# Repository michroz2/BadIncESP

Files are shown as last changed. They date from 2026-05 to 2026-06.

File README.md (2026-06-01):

# BadIncESP - Wireless BLE Inclinometer System

[🇷🇺 Русский](#русский) | [🇬🇧 English](#english)

---

## 🇷🇺 Русский

### Описание проекта
**BadIncESP** — это высокоточная двухмодульная беспроводная система измерения и визуализации углов наклона (инклинометр). Цель - обеспечить визуальный контроль «горизонта» при работе со стэдикамом. Может также использоваться для другой фото-видео аппаратуры и проч. Проект разработан для работы в реальном времени с минимальными задержками и состоит из 2-х модулей: передатчика (с безинерционным датчиком углов) и приемника (индикатора), связанных по протоколу Bluetooth Low Energy (BLE).
Система включает фильтр, который автоматически гасит показания крена, если устройство наклоняется вперед или назад.

### Архитектура системы
* **TX Модуль (Передатчик):** Отвечает за опрос I2C-датчика BNO080, вычисление кватернионов, фильтрацию, опрос кнопок управления и работу BLE-сервера. Отправляет данные (Notify) при каждом изменении состояния.
* **RX Модуль (Приемник):** Работает как BLE-клиент с функцией автоматического переподключения. Декодирует команды и выводит плавную анимацию на светодиодную ленту WS2812B (отклонение "капли" от центра с изменением цвета).
* **Память NVS (Preferences):** Все пользовательские настройки (яркость, чувствительность, реверс ленты) и калибровочные нули осей сохраняются в энергонезависимую память обоих устройств. Запись отложена на 15 секунд после последнего действия пользователя по настройке для защиты флэш-памяти от износа.

### Аппаратное обеспечение
| Компонент | Описание / Пин |
| :--- | :--- |
| **TX Микроконтроллер** | ESP32-S3-Zero |
| **Датчик IMU** | BNO080 (I2C: SDA - GPIO5, SCL - GPIO6) |
| **Кнопка управления** | Тактовая кнопка (GPIO9) |
| **Индикатор кнопки (TX)** | Обычный LED (GPIO10) |
| **Системный LED (TX/RX)** | Встроенный WS2812 (GPIO21) или GPIO2 (WROOM) |
| **RX Микроконтроллер** | ESP32-S3-Zero (или NodeMCU ESP32-WROOM) |
| **Основной Индикатор** | Лента WS2812B, 13 светодиодов (Пин данных: GPIO7 или GPIO13) |

### Динамическое демпфирование (Вторая ось)
Вычислитель TX имеет встроенный фильтр тангажа (наклон вперед/назад):
* **0° – 5°:** Зона нечувствительности. Показания крена точны на 100%.
* **5° – 45°:** Зона пропорционального гашения. Показания крена плавно умножаются на понижающий коэффициент от 1.0 до 0.0.
* **> 45°:** Полное гашение. Индикатор крена принудительно устанавливается в центр (0°), независимо от реального угла устройства.

### Управление и Настройка (Кнопка на TX)
Все настройки осуществляются единственной кнопкой на модуле передатчика.

| Действие | Функция | Индикация на ленте (RX) |
| :--- | :--- | :--- |
| **Короткое нажатие (Клик)** | Изменение яркости (4 уровня) | Мгновенное изменение яркости всей ленты |
| **Двойной клик** | Изменение чувствительности (4 уровня) | Симметричное отображение цвета по краям ленты |
| **Удержание (менее 3 сек)** | Установка нового "нуля" (Калибровка) | Вся лента загорается **СИНИМ** цветом |
| **Долгое удержание (> 3 сек)** | Реверс отображения (Смена сторон) | Левая и правая стороны ленты мигают красным/синим |

### Системная LED Индикация (Статус BLE)
Встроенные светодиоды на платах показывают состояние радиоканала:

| Состояние | Цвет системного LED |
| :--- | :--- |
| **Инициализация / Запуск** | Зеленый |
| **Поиск / Ожидание связи (Advertising/Scanning)** | Красный (или мигающий синий на WROOM) |
| **Соединение установлено** | Синий (непрерывный) |
| **Запись в память NVS (RX)** | Центральный пиксель ленты мигает красным 2 раза |

---

## 🇬🇧 English

### Project Overview
**BadIncESP** is a high-precision, dual-module wireless inclinometer system. Designed for real-time operation with minimal latency, it consists of a transmitter (sensor module) and a receiver (indicator module) connected via Bluetooth Low Energy (BLE).

The system not only broadcasts the primary roll angle but also features a built-in mathematical filter (dynamic damping) that automatically zeroes out the roll readings if the device is excessively pitched forward or backward.

### System Architecture
* **TX Module (Transmitter):** Handles BNO080 I2C sensor polling, quaternion math, dynamic filtering, button control logic, and acts as the BLE Server. Dispatches data via BLE Notify instantly upon state changes.
* **RX Module (Receiver):** Operates as a BLE Client with an auto-reconnect routine. Decodes incoming commands and drives smooth animations on a WS2812B LED strip (a shifting "drop" of light indicating angle and severity via color).
* **NVS Memory (Preferences):** User configurations (brightness, sensitivity, strip reverse) and calibration zeroes are saved to non-volatile memory on both devices. Writes are delayed by 15 seconds after the last user input to prevent flash wear.

### Hardware Requirements
| Component | Description / Pin Assignment |
| :--- | :--- |
| **TX Microcontroller** | ESP32-S3-Zero |
| **IMU Sensor** | BNO080 (I2C: SDA - GPIO5, SCL - GPIO6) |
| **Control Button** | Tactile Switch (GPIO9) |
| **Button Feedback (TX)** | Standard LED (GPIO10) |
| **System LED (TX/RX)** | Onboard WS2812 (GPIO21) or GPIO2 (WROOM) |
| **RX Microcontroller** | ESP32-S3-Zero (or NodeMCU ESP32-WROOM) |
| **Main Indicator** | WS2812B Strip, 13 LEDs (Data Pin: GPIO7 or GPIO13) |

### Dynamic Damping (Y-Axis Filter)
The TX processor includes a pitch (forward/backward tilt) filter:
* **0° – 5°:** Deadzone. Roll readings are 100% accurate and unaffected.
* **5° – 45°:** Proportional damping zone. The roll output is smoothly multiplied by a reduction factor from 1.0 down to 0.0.
* **> 45°:** Complete damping. The roll indicator is forced to the center (0°), regardless of the actual device roll.

### Controls & Configuration (TX Button)
All system settings are managed via a single button on the Transmitter module.

| Action | Function | RX Strip Indication |
| :--- | :--- | :--- |
| **Single Click** | Change Brightness (4 levels) | Immediate brightness update across the strip |
| **Double Click** | Change Sensitivity (4 levels) | Symmetrical color blocks light up on the strip edges |
| **Hold (< 3 sec) & Release** | Set Calibration "Zero" | The entire strip flashes **BLUE** |
| **Long Hold (> 3 sec)** | Reverse Display (Swap Left/Right) | Left and right halves alternate Red/Blue |

### System LED Status (BLE Link)
Onboard processor LEDs provide immediate feedback on the radio link status:

| State | System LED Color |
| :--- | :--- |
| **Booting / Init** | Green |
| **Scanning / Advertising (No Link)** | Red (or flashing Blue on WROOM boards) |
| **BLE Connected** | Blue (Solid) |
| **NVS Memory Write (RX)** | The center LED of the strip flashes Red twice |

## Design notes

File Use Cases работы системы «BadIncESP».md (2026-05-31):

### **Use Cases работы системы «BadIncESP»**

#### **1\. Включение, инициализация**

* **Действия TX:** 1\. Инициализация шины I2C и датчика BNO080. 2\. Чтение из энергонезависимой памяти (EEPROM) сохраненных настроек: яркость (`curFade`), чувствительность (`curSensitivity`), инверсия (`revers`), угол калибровки нуля (`deltaZero`). 3\. Инициализация радиомодуля (сейчас LoRa, будет BLE). 4\. Отправка команды приветствия `CMD_GREETING` на RX.  
* **Действия RX:**  
  1. Чтение из энергонезависимой памяти своих копий настроек (яркость, чувствительность, инверсия).  
  2. Инициализация светодиодной ленты WS2812B с сохраненной яркостью.  
  3. Инициализация радиомодуля на приём.  
  4. При получении `CMD_GREETING` — проигрывание анимации приветствия (пробегание красного, зеленого, синего цветов по всей ленте). Запуск таймера перехода в спящий режим (StandByTime \= 30 сек).

#### **2\. Основная работа (получение, пересылка углов, индикация)**

* **Действия TX:**  
  1. Непрерывный опрос датчика BNO080 (Pitch/Roll).  
  2. Применение к полученному углу поправки `deltaZero` (калибровки).  
  3. Вычисление номера режима индикации (`curMode` от 0 до 22\) на основе текущего угла и выбранной таблицы чувствительности (`modeRange`).  
  4. Если вычисленный `curMode` изменился по сравнению с предыдущим шагом, отправка команды `CMD_MODE` с новым значением по радиоканалу.  
* **Действия RX:**  
  1. Ожидание команд по радиоканалу.  
  2. При получении `CMD_MODE`: обновление таймера спящего режима. Копирование паттерна свечения из массива `modes` согласно полученному индексу.  
  3. Если включен реверс (`revers`), паттерн разворачивается зеркально.  
  4. Вывод паттерна на ленту (`FastLED.show()`).  
  5. Если команды не поступают более 30 секунд: RX показывает анимацию отключения (мигание синим по центру) и гасит ленту до получения новых данных.

#### **3\. Настройки системы (Нажатия кнопки на TX)**

Вся обработка нажатий кнопки физически происходит на модуле TX. RX только показывает анимации и обновляет переменные.

* **Короткое нажатие (Изменение яркости):**  
  * *TX:* Переключает `curFade` (циклично), отправляет `CMD_BRIGHTNESS`, запускает таймер отложенной записи в память (15 секунд).  
  * *RX:* Применяет новую глобальную яркость к ленте, перерисовывает текущий паттерн крена.  
* **Двойное нажатие (Изменение чувствительности):**  
  * *TX:* Переключает `curSensitivity` (циклично), отправляет `CMD_SENSITIVITY`, запускает таймер записи в память.  
  * *RX:* Показывает анимацию чувствительности (симметрично загораются 2 светодиода, расстояние между которыми зависит от уровня чувствительности).  
* **Длинное нажатие — Удержание (Подготовка к калибровке):**  
  * *TX:* Фиксирует старт долгого нажатия, отправляет `CMD_LONGPRESS`. Запускает таймер 3 секунды.  
  * *RX:* Показывает «двойную радугу» (`modeLongPressStart`).  
* **Длинное нажатие — Отпускание до 3-х секунд (Калибровка нуля):**  
  * *TX:* Останавливает опросы. Делает 100 замеров с датчика BNO080, вычисляет среднее значение и записывает его в `deltaZero`. Отправляет `CMD_CALIBRATION`. Запускает таймер записи в память.  
  * *RX:* Заливает всю ленту синим цветом в знак успешной калибровки.  
* **Очень длинное нажатие — Более 3-х секунд (Инверсия сторон):**  
  * *TX:* Инвертирует флаг `revers`, отправляет `CMD_SWITCHSIDES`. Отменяет режим калибровки. Запускает таймер записи в память.  
  * *RX:* Проигрывает анимацию смены сторон (синяя и красная половины ленты меняются местами).  
* **Автоматическое сохранение (Отложенная запись):**  
  * *TX:* Если с момента последней настройки прошло 15 секунд (и кнопка не нажималась), TX сохраняет свои настройки в EEPROM и отправляет `CMD_EEPROM_WRITE`.  
  * *RX:* При получении команды показывает анимацию записи (мигание центрального светодиода красным) и сохраняет свои текущие переменные в свой EEPROM.

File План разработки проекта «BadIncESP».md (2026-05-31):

### **План разработки проекта «BadIncESP»**

**Этап 1: Анализ существующей системы и проектирование (Новый шаг)**

* **Шаг 1.1:** Получение текущего кода (TX и RX) и имеющейся документации.  
* **Шаг 1.2:** Изучение логики работы BNO080 и WS2812B в старом коде.  
* **Шаг 1.3:** Составление Use Cases работы системы (включая передачу углов в реальном времени и логику работы кнопки настроек на TX). Утверждение архитектуры взаимодействия.

**Этап 2: Подготовка инфраструктуры и даташитов**

* **Шаг 2.1:** Изучение даташитов ESP32-S3-Zero (распиновка, аппаратные особенности).  
* **Шаг 2.2:** Создание двух чистых проектов PlatformIO (TX и RX) с настройкой конфигураций `platformio.ini`. Фиксация пинов.

**Этап 3: Базовое портирование периферии (Без радиосвязи)**

* **Шаг 3.1 (TX):** Интеграция опроса BNO080 и кнопки. Вывод данных в Serial.  
* **Шаг 3.2 (RX):** Интеграция управления WS2812B (с учетом использования аппаратного RMT ESP32 для избежания блокировок). Тестовая индикация.

**Этап 4: Разработка канала связи BLE на максимальной скорости**

* **Шаг 4.1 (TX \- Server):** Поднятие BLE Сервера, создание сервиса и характеристик для углов и команд кнопки. Настройка механизма Notify.  
* **Шаг 4.2 (RX \- Client):** Поднятие BLE Клиента, подключение к TX, подписка на Notify. Вывод получаемых данных в Serial.

**Этап 5: Полная интеграция системы**

* Связывание потока данных BLE (RX) с логикой отображения WS2812B.  
* Тестирование скорости отклика, обработка потери/восстановления связи.

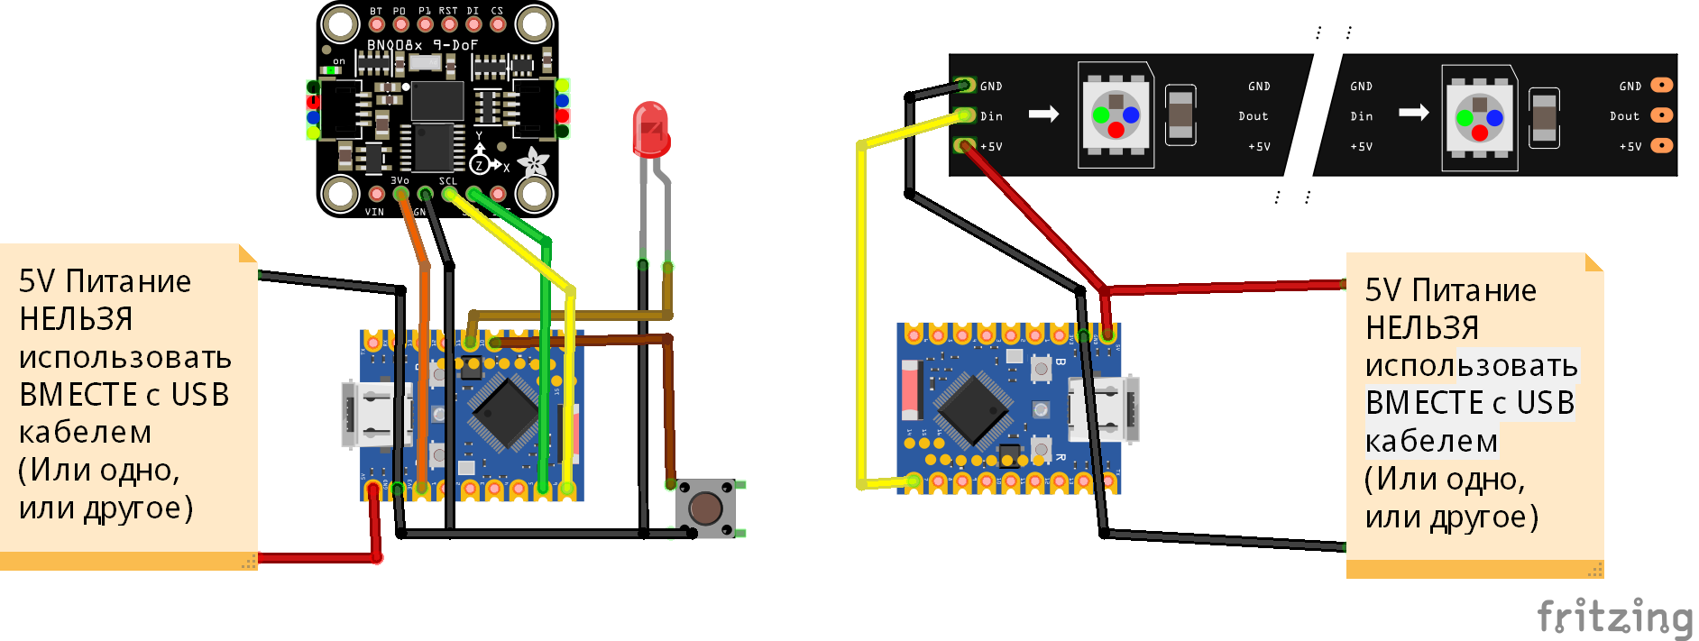
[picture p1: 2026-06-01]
BadIncESP_bb.png

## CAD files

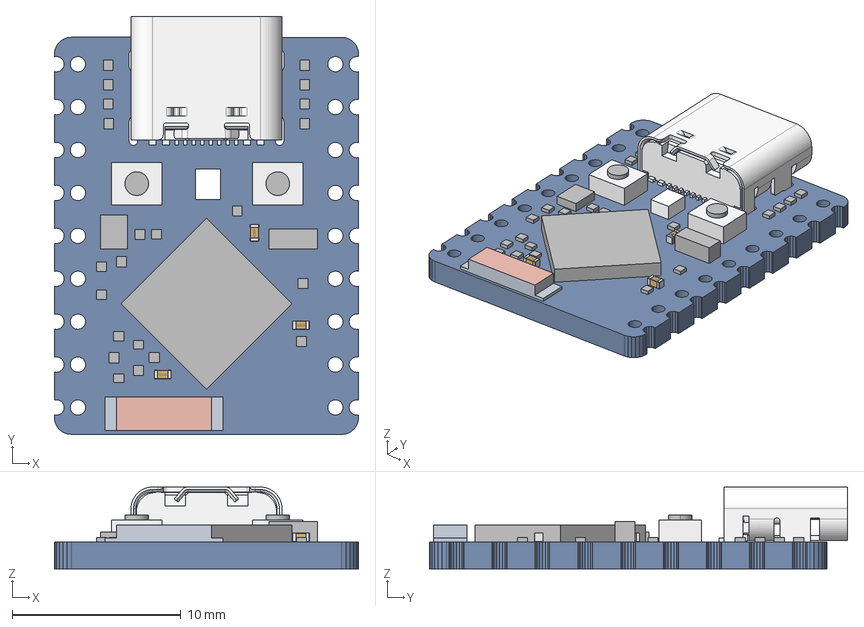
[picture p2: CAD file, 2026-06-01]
ESP32-S3-Zero_v2-138eb3753cf14afa3252058c380ca416.stp
18.0 x 24.7 x 4.85 mm
BOARD
EXTRUDED-21020 x 13
EXTRUDED-21415 x 7
3_1_A x 3
EXTRUDED-58116 x 2
EXTRUDED-58651
EXTRUDED-59046
EXTRUDED-59609
TYPE-C_16PIN-9X3X7_3
PRT0001
C3
BUTTON-2X3XH1_5

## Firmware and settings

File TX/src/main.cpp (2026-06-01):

/**
 * @file main.cpp
 * @project BadIncESP - Модуль TX (Датчик и вычислитель)
 * @version 1.6
 * * @changelog
 * v1.6 - Реализовано плавное гашение угла по оси Y в диапазоне 5-45 градусов.
 * - Добавлена калибровка нуля для оси Y (deltaZero_Y) с сохранением в Preferences.
 * v1.5 - Замена старой EEPROM на Preferences.h. Отложенная запись 15 секунд.
 * v1.1.1 - Исправление BLE: включен ScanResponse(true) для передачи UUID.
 * v1.1 - Замена LoRa на BLE Server с Notify. Статусный RGB LED (GPIO 21).
 * v1.0 - Первичное портирование периферии (BNO080, Кнопка, Статусный LED).
 */

 #include <Arduino.h>
 #include <Wire.h>
 #include "SparkFun_BNO080_Arduino_Library.h"
 #include <OneButton.h>
 #include <FastLED.h>
 #include <Preferences.h> 
 
 // Подключение библиотек BLE
 #include <BLEDevice.h>
 #include <BLEServer.h>
 #include <BLEUtils.h>
 #include <BLE2902.h>
 
 // ================= ОПРЕДЕЛЕНИЕ ВЕРСИИ И ТИПА МОДУЛЯ =================
 #define MODULE_TYPE "TX (ДАТЧИК)"
 #define VERSION     "1.6"
 
 // ================= НАСТРОЙКИ ПИНОВ ESP32-S3 =================
 #define PIN_I2C_SDA 5
 #define PIN_I2C_SCL 6
 #define PIN_CONTROL_BUTTON 9
 #define PIN_FB_LED 10
 #define PIN_SYS_LED 21  // Встроенный адресный RGB LED
 
 // ================= НАСТРОЙКИ BLE =================
 #define SERVICE_UUID        "4fafc201-1fb5-459e-8fcc-c5c9c331914b"
 #define CHARACTERISTIC_UUID "beb5483e-36e1-4688-b7f5-ea07361b26a8"
 
 BLEServer* pServer = NULL;
 BLECharacteristic* pCharacteristic = NULL;
 bool deviceConnected = false;
 bool oldDeviceConnected = false;
 
 // ================= ОСНОВНЫЕ НАСТРОЙКИ =================
 #define USE_X_AXIS 1  
 #define USE_Y_AXIS 0  
 bool usedAxis = USE_X_AXIS;    
 
 #define FB_LED_BRIGHTNESS 30   
 #define NUM_MODES 23           
 #define NUM_FADES 4            
 #define NUM_SENSITIVITIES 4    
 #define VERY_LONG_PRESS_MS 3000 
 
 // ================= НАСТРОЙКИ ГАШЕНИЯ ПО ОСИ Y =================
 const float DEADZONE_ANGLE_Y = 5.0f;      // До этого угла (градусы) влияние Y игнорируется
 const float MAX_DAMPING_ANGLE_Y = 45.0f;  // При этом угле и выше, основной угол принудительно гасится в 0.0
 
 // Команды для связи
 #define CMD_BRIGHTNESS       100 
 #define CMD_SENSITIVITY      101 
 #define CMD_SWITCHSIDES      102 
 #define CMD_LONGPRESS        103 
 #define CMD_CALIBRATION      104 
 #define CMD_MODE             111 
 #define CMD_GREETING         112 
 #define CMD_EEPROM_WRITE     113 
 
 // Настройки таймера сохранения памяти NVS
 #define WRITE_PREFERENCES_DELAY_MS 15000 
 Preferences prefs;
 bool writePrefsPending = false;
 uint32_t writePrefsTimer = 0;
 
 // Дефолтные значения параметров
 const byte defaultFade = 0;
 const byte defaultSensitivity = 0;
 const boolean defaultReverse = false;
 const float defaultDeltaZero = 0.0f;
 
 // ================= ГЛОБАЛЬНЫЕ ОБЪЕКТЫ =================
 BNO080 myIMU;
 OneButton buttonControl(PIN_CONTROL_BUTTON, true);
 CRGB sysLed[1]; 
 
 // ================= ГЛОБАЛЬНЫЕ ПЕРЕМЕННЫЕ СОСТОЯНИЯ =================
 byte curFade = defaultFade; 
 byte curMode = NUM_MODES / 2; 
 byte prevMode = -1; 
 float Roll = 0.0f;   
 float deltaZero = defaultDeltaZero; 
 float deltaZero_Y = defaultDeltaZero; // Калибровочный ноль перпендикулярной оси Y
 boolean revers = defaultReverse;   
 byte curSensitivity = defaultSensitivity;    
 
 boolean startCalibrationMode = false;
 uint32_t verylongPressTimer = 0;
 
 uint8_t fades[NUM_FADES] = {255, 64, 32, 8}; 
 
 const float modeRange[NUM_SENSITIVITIES][NUM_MODES - 1] PROGMEM = 
 {
   {10, 5.0, 2.2, 1.6, 1.1, 0.8, 0.6, 0.4, 0.3, 0.2, 0.1,  -0.1, -0.2, -0.3, -0.4, -0.6, -0.8, -1.1, -1.6, -2.2, -5.0, -10},
   {10, 5.0, 2.8, 2.1, 1.5, 1.1, 0.8, 0.5, 0.4, 0.3, 0.2,  -0.2, -0.3, -0.4, -0.5, -0.8, -1.1, -1.5, -2.1, -2.8, -5.0, -10},
   {10, 5.0, 3.4, 2.6, 1.9, 1.4, 1.0, 0.6, 0.5, 0.4, 0.3,  -0.3, -0.4, -0.5, -0.6, -1.0, -1.4, -1.9, -2.6, -3.4, -5.0, -10},
   {12, 6.0, 4.0, 3.1, 2.3, 1.7, 1.2, 0.7, 0.6, 0.5, 0.4,  -0.4, -0.5, -0.6, -0.7, -1.2, -1.7, -2.3, -3.1, -4.0, -6.0, -12},
 };
 
 // ================= ПРОТОТИПЫ ФУНКЦИЙ =================
 void updateFBLed(bool ledStatus);
 void flashFBLed(int times);
 void setSysLed(CRGB color);
 void sendLoRaMessage(byte msgCmd, byte sndData);
 void preparePreferencesWrite();
 void processPreferences();
 void loadSettings();
 void saveSettings();
 void setZERO();
 
 // ================= CALLBACKS ДЛЯ BLE =================
 class MyServerCallbacks: public BLEServerCallbacks {
     void onConnect(BLEServer* pServer) {
       deviceConnected = true;
     };
     void onDisconnect(BLEServer* pServer) {
       deviceConnected = false;
     }
 };
 
 // ================= РАБОТА С ЭНЕРГОНЕЗАВИМОЙ ПАМЯТЬЮ (NVS) =================
 void loadSettings() {
   Serial.println("Чтение настроек из памяти NVS...");
   prefs.begin("badinc", true); 
   
   curFade = prefs.getUChar("fade", defaultFade);
   curSensitivity = prefs.getUChar("sens", defaultSensitivity);
   revers = prefs.getBool("rev", defaultReverse);
   deltaZero = prefs.getFloat("zero", defaultDeltaZero);
   deltaZero_Y = prefs.getFloat("zero_y", defaultDeltaZero); // Загрузка нуля оси Y
   
   prefs.end();
 
   Serial.printf("Загружено: Яркость=%d, Чувствительность=%d, Реверс=%d, Ноль_X=%6.2f°, Ноль_Y=%6.2f°\n", 
                 curFade, curSensitivity, revers, deltaZero, deltaZero_Y);
 }
 
 void saveSettings() {
   Serial.println("ФАКТИЧЕСКОЕ СОХРАНЕНИЕ настроек в память NVS...");
   prefs.begin("badinc", false); 
   
   prefs.putUChar("fade", curFade);
   prefs.putUChar("sens", curSensitivity);
   prefs.putBool("rev", revers);
   prefs.putFloat("zero", deltaZero);
   prefs.putFloat("zero_y", deltaZero_Y); // Сохранение нуля оси Y
   
   prefs.end();
   Serial.println("Сохранение успешно выполнено.");
 }
 
 void preparePreferencesWrite() {
   writePrefsPending = true;
   writePrefsTimer = millis() + WRITE_PREFERENCES_DELAY_MS;
   Serial.println("Память: запланирована отложенная запись через 15 секунд.");
 }
 
 void processPreferences() {
   if (writePrefsPending && (millis() > writePrefsTimer)) {
     writePrefsPending = false;
     saveSettings();
     sendLoRaMessage(CMD_EEPROM_WRITE, 0);
     flashFBLed(3); 
     prevMode = -1; 
   }
 }
 
 // ================= АППАРАТНЫЕ ФУНКЦИИ (LEDs) =================
 void initFBled() {
   pinMode(PIN_FB_LED, OUTPUT);
   analogWrite(PIN_FB_LED, 0); 
   updateFBLed(1);
 }
 
 void updateFBLed(bool ledStatus) {
   analogWrite(PIN_FB_LED, ledStatus ? FB_LED_BRIGHTNESS : 0);
 }
 
 void flashFBLed(int times) {
   bool flash = false;
   for (int i = 0; i < times * 2; i++) {
     flash = !flash;
     updateFBLed(flash);
     delay(200);
   }
   delay(200);
 }
 
 void setSysLed(CRGB color) {
   sysLed[0] = color;
   FastLED.show();
 }
 
 // ================= ФУНКЦИИ СВЯЗИ BLE =================
 void sendLoRaMessage(byte msgCmd, byte sndData) {
   if (deviceConnected) {
     uint8_t packet[2];
     packet[0] = msgCmd;
     packet[1] = sndData;
     pCharacteristic->setValue(packet, 2);
     pCharacteristic->notify(); 
     Serial.printf("[BLE] Отправлено: Cmd=%d, Data=%d\n", msgCmd, sndData);
   } else {
     Serial.printf("[BLE] Нет связи. Пропуск отправки: Cmd=%d\n", msgCmd);
   }
 }
 
 // ================= ИНИЦИАЛИЗАЦИЯ ПЕРИФЕРИИ =================
 void initWire() {
   Wire.begin(PIN_I2C_SDA, PIN_I2C_SCL); 
   Wire.setClock(400000); 
   delay(100);
 }
 
 void initIMU() {
   if (myIMU.begin() == false) {
     Serial.println("ОШИБКА: BNO080 не найден!");
     setSysLed(CRGB::Red);
     while (1) { delay(10); } 
   }
   myIMU.enableGameRotationVector(25); 
   delay(200);
   myIMU.enableStabilityClassifier(25); 
   delay(200);
 }
 
 void initBLE() {
   BLEDevice::init("BadIncESP_TX");
   pServer = BLEDevice::createServer();
   pServer->setCallbacks(new MyServerCallbacks());
 
   BLEService *pService = pServer->createService(SERVICE_UUID);
   pCharacteristic = pService->createCharacteristic(
                       CHARACTERISTIC_UUID,
                       BLECharacteristic::PROPERTY_NOTIFY
                     );
   pCharacteristic->addDescriptor(new BLE2902());
   pService->start();
   
   BLEAdvertising *pAdvertising = BLEDevice::getAdvertising();
   pAdvertising->addServiceUUID(SERVICE_UUID); 
   pAdvertising->setScanResponse(true);        
   pAdvertising->setMinPreferred(0x06);        
   pAdvertising->setMaxPreferred(0x12);
   BLEDevice::startAdvertising();
   Serial.println("BLE Сервер запущен. Ожидание подключения...");
 }
 
 // ================= ФУНКЦИИ КНОПКИ настроек =================
 void clickControl() {
   curFade = (curFade + 1) % NUM_FADES;
   sendLoRaMessage(CMD_BRIGHTNESS, curFade);
   flashFBLed(1);
   prevMode = -1;
   preparePreferencesWrite();
 }
 
 void doubleclickControl() {
   curSensitivity = (curSensitivity + 1) % NUM_SENSITIVITIES;
   sendLoRaMessage(CMD_SENSITIVITY, curSensitivity);
   flashFBLed(2);
   prevMode = -1;
   preparePreferencesWrite();
 }
 
 void switchSides() {
   revers = !revers;
   sendLoRaMessage(CMD_SWITCHSIDES, revers);
   flashFBLed(2);
   prevMode = -1;
 }
 
 void longPressStartControl() {
   startCalibrationMode = true;
   verylongPressTimer = millis() + VERY_LONG_PRESS_MS;
   sendLoRaMessage(CMD_LONGPRESS, 1);
   flashFBLed(4);
 }
 
 void longPressControl() {
   if (millis() > verylongPressTimer) {
     verylongPressTimer = millis() + VERY_LONG_PRESS_MS; 
     startCalibrationMode = false;
     switchSides();
     preparePreferencesWrite();
   }
 }
 
 void longPressStopControl() {
   if (startCalibrationMode) {
     startCalibrationMode = false;
     sendLoRaMessage(CMD_CALIBRATION, 1);
     flashFBLed(2);
     prevMode = -1;
     preparePreferencesWrite();
     setZERO();
   }
 }
 
 void initButtons() {
   buttonControl.attachClick(clickControl);
   buttonControl.attachDoubleClick(doubleclickControl);
   buttonControl.attachLongPressStart(longPressStartControl);
   buttonControl.attachLongPressStop(longPressStopControl);
   buttonControl.attachDuringLongPress(longPressControl);
 }
 
 // ================= МАТЕМАТИКА ДАТЧИКА =================
 void setZERO() {
   byte moving_status = 5;
   do {
     delay(200);
     if (myIMU.dataAvailable()) {
       moving_status = myIMU.getStabilityClassifier();
     }
   } while (moving_status > 3);
 
   float delta0 = 0;
   float delta0_Y = 0;
   for (int i = 0; i < 100; i++) {
     delta0   += (usedAxis ? myIMU.getPitch() : myIMU.getRoll());
     delta0_Y += (usedAxis ? myIMU.getRoll() : myIMU.getPitch());
     delay(50);
   }
   deltaZero = (delta0 * 180.0 / PI) / 100.0;
   deltaZero_Y = (delta0_Y * 180.0 / PI) / 100.0; // Одновременная фиксация нуля Y
   Serial.printf("Калибровка выполнена. Новые нули: X=%6.2f°, Y=%6.2f°\n", deltaZero, deltaZero_Y);
 }
 
 void getNextRoll() {
   if (myIMU.dataAvailable()) {
     // 1. Получаем физические значения углов в градусах с учетом индивидуальных нулей
     Roll = (usedAxis ? myIMU.getPitch() : myIMU.getRoll()) * 57.29578 - deltaZero;
     float Pitch_Y = (usedAxis ? myIMU.getRoll() : myIMU.getPitch()) * 57.29578 - deltaZero_Y;
 
     // 2. Вычисляем модуль отклонения по перпендикулярной оси Y
     float absY = abs(Pitch_Y);
     float dampingFactor = 1.0f; 
 
     // 3. Линейная интерполяция коэффициента гашения
     if (absY >= MAX_DAMPING_ANGLE_Y) {
       dampingFactor = 0.0f; // Полное обнуление крена при 45 градусах тангажа и выше
     } 
     else if (absY > DEADZONE_ANGLE_Y) {
       // Пропорциональное уменьшение множителя от 1.0 до 0.0
       dampingFactor = 1.0f - ((absY - DEADZONE_ANGLE_Y) / (MAX_DAMPING_ANGLE_Y - DEADZONE_ANGLE_Y));
     }
 
     // 4. Модифицируем главный рабочий угол коэффициентом демпфирования
     Roll *= dampingFactor;
   }
 }
 
 byte getMode() {
   for (byte i = 0; i < (NUM_MODES - 1); i++) {
     if (Roll > modeRange[curSensitivity][i]) {
       return i;
     }
   }
   return (NUM_MODES - 1);
 }
 
 // ================= ОСНОВНОЙ ЦИКЛ СИСТЕМЫ =================
 void setup() {
   Serial.begin(115200);
   delay(2000); 
   
   Serial.println("\n========================================");
   Serial.printf("=== ПРОЕКТ BadIncESP | МОДУЛЬ: %s ===\n", MODULE_TYPE);
   Serial.printf("=== ВЕРСИЯ ПРОШИВКИ: %s                  ===\n", VERSION);
   Serial.println("========================================");
 
   FastLED.addLeds<WS2812B, PIN_SYS_LED, GRB>(sysLed, 1);
   FastLED.setBrightness(50);
   setSysLed(CRGB::Green); 
 
   initWire();
   initButtons();
   initFBled();
   loadSettings(); 
   initIMU();
   initBLE();
   
   flashFBLed(1);
   sendLoRaMessage(CMD_GREETING, 0); 
 }
 
 void loop() {
   buttonControl.tick();
   
   if (deviceConnected && !oldDeviceConnected) {
       oldDeviceConnected = true;
       setSysLed(CRGB::Blue); 
       Serial.println("RX Приемник подключился!");
       prevMode = -1; 
   }
   if (!deviceConnected && oldDeviceConnected) {
       delay(500); 
       pServer->startAdvertising(); 
       oldDeviceConnected = false;
       setSysLed(CRGB::Red); 
       Serial.println("RX Отключился. Повторный запуск Advertising...");
   }
   
   getNextRoll();
   curMode = getMode();
   
   if (curMode != prevMode) {
     sendLoRaMessage(CMD_MODE, curMode);
     prevMode = curMode;
   }
   
   processPreferences(); 
   delay(1); // Оптимизированный такт цикла
 }

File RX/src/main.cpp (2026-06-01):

/**
 * @file main.cpp
 * @project BadIncESP - Модуль RX (Индикатор)
 * @version 1.6
 * * @changelog
 * v1.6 - Синхронизация версии экосистемы (логика вынесена на сторону TX).
 * v1.5 - Замена старой EEPROM на Preferences.h. Мгновенная локальная запись.
 * v1.2.1 - Исправление BLE: асинхронный запуск сканера. Отладочный вывод статуса.
 * v1.2 - Внедрена поддержка двух аппаратных плат (WROOM и S3-Zero).
 * - Интегрирована защита от просадки напряжения при запуске (Brownout).
 */

 #include <Arduino.h>
 #include <FastLED.h>
 #include <BLEDevice.h>
 #include <Preferences.h> 
 
 // ================= ВЫБОР АППАРАТНОЙ ПЛАТЫ =================
 #define USE_WROOM_BOARD
 
 #ifdef USE_WROOM_BOARD
   #define PIN_LEDS 13     
   #define PIN_SYS_LED 2   
 #else
   #define PIN_LEDS 7      
   #define PIN_SYS_LED 21  
 #endif
 
 // ================= ОПРЕДЕЛЕНИЕ ВЕРСИИ И ТИПА МОДУЛЯ =================
 #define MODULE_TYPE "RX (ИНДИКАТОР)"
 #define VERSION     "1.6"
 
 // ================= НАСТРОЙКИ BLE =================
 #define SERVICE_UUID        "4fafc201-1fb5-459e-8fcc-c5c9c331914b"
 #define CHARACTERISTIC_UUID "beb5483e-36e1-4688-b7f5-ea07361b26a8"
 
 static boolean doConnect = false;
 static boolean connected = false;
 static boolean doScan = false;
 static BLERemoteCharacteristic* pRemoteCharacteristic;
 static BLEAdvertisedDevice* myDevice;
 
 enum SystemState { STATE_INIT, STATE_SCANNING, STATE_CONNECTED };
 SystemState currentState = STATE_INIT;
 
 // ================= ОСНОВНЫЕ НАСТРОЙКИ =================
 #define NUM_LEDS 13   
 #define NUM_MODES 23  
 #define NUM_FADES 4   
 #define NUM_SENSITIVITIES 4 
 
 unsigned long StandByTime = 30000; 
 unsigned long nextStandByMillis;
 
 // Команды связи
 #define CMD_BRIGHTNESS       100 
 #define CMD_SENSITIVITY      101 
 #define CMD_SWITCHSIDES      102 
 #define CMD_LONGPRESS        103 
 #define CMD_CALIBRATION      104 
 #define CMD_MODE             111 
 #define CMD_GREETING         112 
 #define CMD_EEPROM_WRITE     113 
 
 // Настройки памяти NVS
 Preferences prefs;
 const byte defaultFade = 0;
 const byte defaultSensitivity = 0;
 const boolean defaultReverse = false;
 
 // Кольцевой буфер команд
 #define MAX_INDEX 8
 byte rcvCmd[MAX_INDEX];      
 byte rcvData[MAX_INDEX];     
 byte rcvIndex = 0, curIndex = 0;    
 boolean StandBy = false;            
 
 byte curFade = defaultFade; 
 byte curMode = NUM_MODES / 2; 
 byte prevMode = -1; 
 boolean revers = defaultReverse;   
 byte curSensitivity = defaultSensitivity;    
 
 uint8_t fades[NUM_FADES] = {255, 64, 32, 8}; 
 CRGB leds[NUM_LEDS];
 #ifndef USE_WROOM_BOARD
 CRGB sysLed[1]; 
 #endif
 
 // ================= МАССИВЫ ЦВЕТОВ =================
 CRGB modes[NUM_MODES][NUM_LEDS] = {
   {0xff0000, 0x640800, 0x321400,        0,        0,        0,        0,        0, 0, 0, 0, 0, 0}, 
   {0xff0000, 0x8c0000, 0x500a00, 0x3c1400, 0x200800,        0,        0,        0, 0, 0, 0, 0, 0}, 
   {0xff0000, 0x780000, 0x641000, 0x321E00, 0x180E00, 0x0F1400, 0x000400,        0, 0, 0, 0, 0, 0}, 
   {0x0a0000, 0x780000, 0x641000, 0x321E00, 0x321E00, 0x1E2D00, 0x000C00,        0, 0, 0, 0, 0, 0}, 
   {0x040000, 0x080000, 0x641000, 0x501E00, 0x463200, 0x283C00, 0x001E00,        0, 0, 0, 0, 0, 0}, 
   {0,        0x040000, 0x080000, 0x501E00, 0x5A4600, 0x3C5000, 0x003200,        0, 0, 0, 0, 0, 0}, 
   {0,        0,        0x040000, 0x501E00, 0x786400, 0x506400, 0x005000,        0, 0, 0, 0, 0, 0}, 
   {0,        0,        0,        0x321E00, 0x786400, 0x647800, 0x007800,        0, 0, 0, 0, 0, 0}, 
   {0,        0,        0,        0,        0x786400, 0x647800, 0x00A000,        0, 0, 0, 0, 0, 0}, 
   {0,        0,        0,        0,        0x2D1E00, 0x647800, 0x00C800,        0, 0, 0, 0, 0, 0}, 
   {0,        0,        0,        0,        0,        0x467800, 0x00FF00,        0, 0, 0, 0, 0, 0}, 
   {0,        0,        0,        0,        0,        0x002020, 0x00FF00, 0x002020, 0, 0, 0, 0, 0}, 
 };
 
 CRGB modeLongPressStart[NUM_LEDS] = {
   CRGB::Red, CRGB::Orange, CRGB::Yellow, CRGB::Green, CRGB::Blue, CRGB::Indigo, CRGB::Violet,
   CRGB::Indigo, CRGB::Blue, CRGB::Green, CRGB::Yellow, CRGB::Orange, CRGB::Red
 };
 
 CRGB testColors[3] = { CRGB::Red, CRGB::Green, CRGB::Blue };
 
 // ================= ПРОТОТИПЫ ФУНКЦИЙ =================
 void showSwitchOff();
 void loadSettings();
 void saveSettings();
 
 // ================= РАБОТА С ЭНЕРГОНЕЗАВИМОЙ ПАМЯТЬЮ (NVS) =================
 void loadSettings() {
   Serial.println("Чтение настроек из памяти NVS RX...");
   prefs.begin("badinc_rx", true); 
   
   curFade = prefs.getUChar("fade", defaultFade);
   curSensitivity = prefs.getUChar("sens", defaultSensitivity);
   revers = prefs.getBool("rev", defaultReverse);
   
   prefs.end();
   Serial.printf("Загружено на RX: Яркость=%d, Чувствительность=%d, Реверс=%d\n", curFade, curSensitivity, revers);
 }
 
 void saveSettings() {
   Serial.println("Сохранение локальных копий параметров в NVS RX...");
   prefs.begin("badinc_rx", false); 
   
   prefs.putUChar("fade", curFade);
   prefs.putUChar("sens", curSensitivity);
   prefs.putBool("rev", revers);
   
   prefs.end();
 }
 
 // ================= СИСТЕМНАЯ СВЕТОДИОДНАЯ ИНДИКАЦИЯ СВЯЗИ =================
 void initSysLed() {
 #ifdef USE_WROOM_BOARD
   pinMode(PIN_SYS_LED, OUTPUT);
 #else
   FastLED.addLeds<WS2812B, PIN_SYS_LED, GRB>(sysLed, 1);
   FastLED.setBrightness(50);
 #endif
 }
 
 void updateSysLed() {
 #ifdef USE_WROOM_BOARD
   if (currentState == STATE_CONNECTED) {
     digitalWrite(PIN_SYS_LED, HIGH);
   } else {
     digitalWrite(PIN_SYS_LED, (millis() / 500) % 2); 
   }
 #else
   static SystemState lastState = (SystemState)-1;
   if (currentState != lastState) {
     if (currentState == STATE_INIT) sysLed[0] = CRGB::Green;
     else if (currentState == STATE_SCANNING) sysLed[0] = CRGB::Red;
     else if (currentState == STATE_CONNECTED) sysLed[0] = CRGB::Blue;
     FastLED.show();
     lastState = currentState;
   }
 #endif
 }
 
 // ================= КОЛЛБЭКИ BLE =================
 static void notifyCallback(
   BLERemoteCharacteristic* pBLERemoteCharacteristic,
   uint8_t* pData,
   size_t length,
   bool isNotify) {
   
   if (length == 2) {
     rcvCmd[rcvIndex] = pData[0];
     rcvData[rcvIndex] = pData[1];
     rcvIndex = (rcvIndex + 1) % MAX_INDEX;
     
     StandBy = false;
     nextStandByMillis = millis() + StandByTime;
   }
 }
 
 class MyClientCallback : public BLEClientCallbacks {
   void onConnect(BLEClient* pclient) { }
   void onDisconnect(BLEClient* pclient) {
     connected = false;
     doScan = true; 
     currentState = STATE_SCANNING;
     Serial.println("Потеряна связь с TX.");
   }
 };
 
 class MyAdvertisedDeviceCallbacks: public BLEAdvertisedDeviceCallbacks {
   void onResult(BLEAdvertisedDevice advertisedDevice) {
     if (advertisedDevice.haveServiceUUID() && advertisedDevice.isAdvertisingService(BLEUUID(SERVICE_UUID))) {
       BLEDevice::getScan()->stop();
       myDevice = new BLEAdvertisedDevice(advertisedDevice);
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

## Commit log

2026-06-01 Step 3.1: TX base hardware porting complete and verified
    [ESP32-S3-Zero_v2-138eb3753cf14afa3252058c380ca416.stp]
2026-06-01 Step 3.2: RX base hardware porting complete and LED strip verified
2026-06-01 Step 6: Implemented dynamic Y-axis damping algorithm (v1.6)
2026-06-01 Refine description of filtering system behavior
2026-06-01 Fritzin and png added
    [BadIncESP.fzz]
